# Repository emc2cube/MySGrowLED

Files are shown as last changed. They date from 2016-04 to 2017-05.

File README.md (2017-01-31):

MySGrowLED
==========

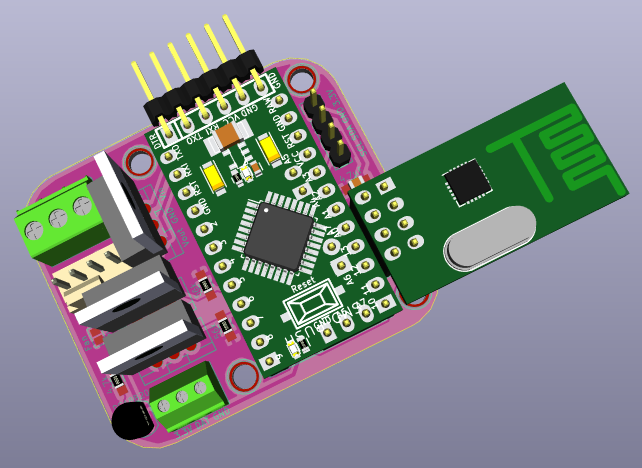
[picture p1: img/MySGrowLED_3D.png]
KiCad 3D view


Description
-----------

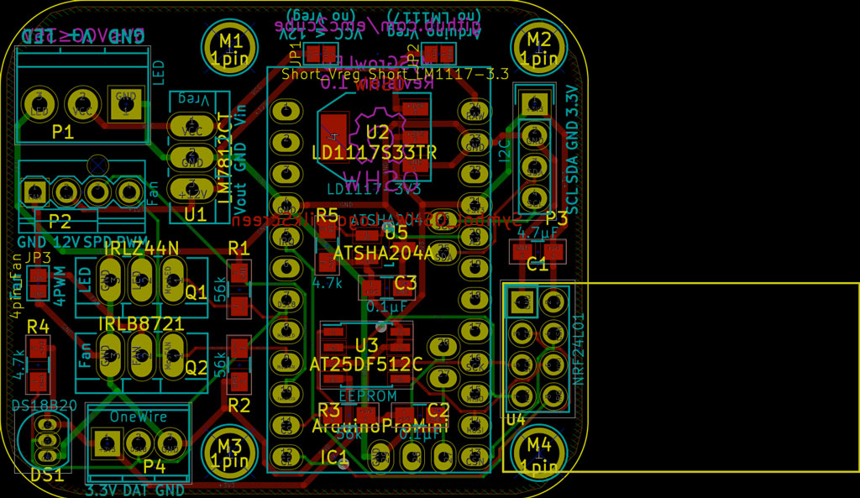
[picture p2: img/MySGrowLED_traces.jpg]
KiCad traces


[MySensors](http://www.mysensors.org) module designed for wireless greenhouse automation (nRF24L01, 2.4GHz).

This module allow you to:
- control a primary LED light (5-40V input can be used to power the module)
- control a secondary circuit designed for a CPU PWM fan but can be used for a second light, humidifier, relay or anything else using 12V
- monitor temperature using an optional onboard DS18b20 sensor
- monitor external temperature by plugging external OneWire sensors
- monitor any additional parameters using additional I2C modules such as temperature, humidity, light levels, barometric pressure, etc...

Ordering
--------

Gerber files are included, so you can order these PCB at your favorite PCB fab house.
For an easy ordering process you can directly order these PCB from different manufacturer without having to do anything:
- [PCBs.io](https://PCBs.io/share/4oldQ) 4 for $11.62, black 1.2mm PCB, ENIG finish.
- [DirtyPCBs](http://dirtypcbs.com/store/designer/details/10880/873/mysgrowled) ~10 for $15.95, multiple colors and PCB thickness, HASL finish.
- [OSH Park](https://oshpark.com/shared_projects/yTV72xyU) 3 for $14.95, purple 1.6mm PCB, ENIG finish.
Components are highly customizable and the default list may not be the best for your specific use, but it will work for most of the cases. Double check that the power supplies, voltage regulators and mosfets are compatible with your project.

Options
-------

This board is designed to be compatible with [MySensors](http://www.mysensors.org) but can be used on its own (timer or sensors to control the lights) or another system using 2.4GHz communication if you adapt the arduino code.

### ATSHA204 module
For security reason you can add a CryptAuthEE SHA256 chip. This will allow you to sign messages and will secure communications between the node and your gateway (this is not encryption, just signing).
If you only control lights, fan, or other non-essential hardware you probably don't need to bother with this chip.
Signing can also be done at the software level, without the chip if you decide to add this function later.

### Eeprom module
This module is only used to perform OTA updates on the node. If you don't plan to use this feature you can also skip this chip.
You will also need to burn a compatible bootloader to your arduino (DualOptiBoot)

Assembly
--------

Once you received your dirty package of PCBs (or any other Fab house) start by inspecting it carefully to look for scratches, dents, or anything that seems wrong. Do not use the board if you have any concerns.
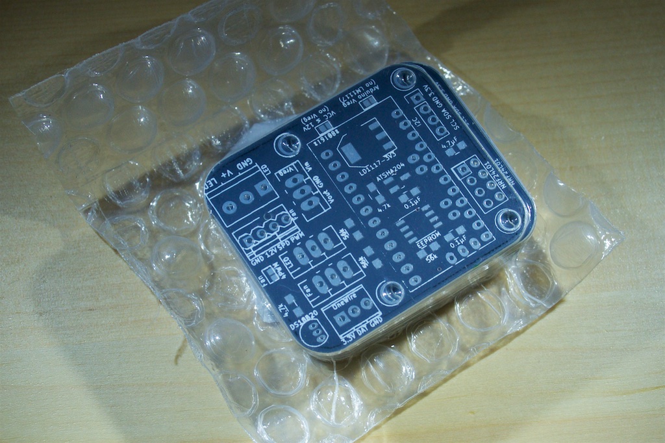
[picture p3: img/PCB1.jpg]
DirtyPackage


Markings are a little off, but nothing wrong on this one, good to go!
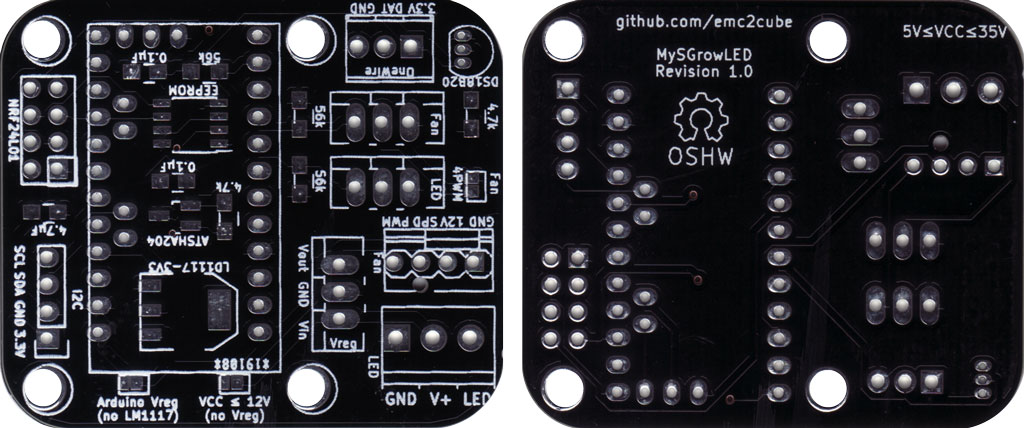
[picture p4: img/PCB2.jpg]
PCB RV


Start by soldering the optional chips, if you plan to use them.
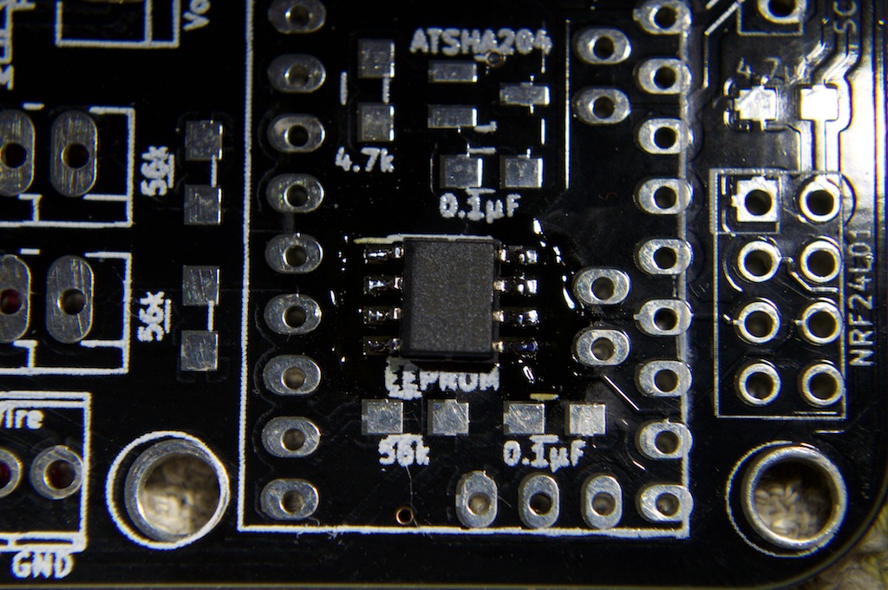
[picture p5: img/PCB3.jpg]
Eeprom soldering

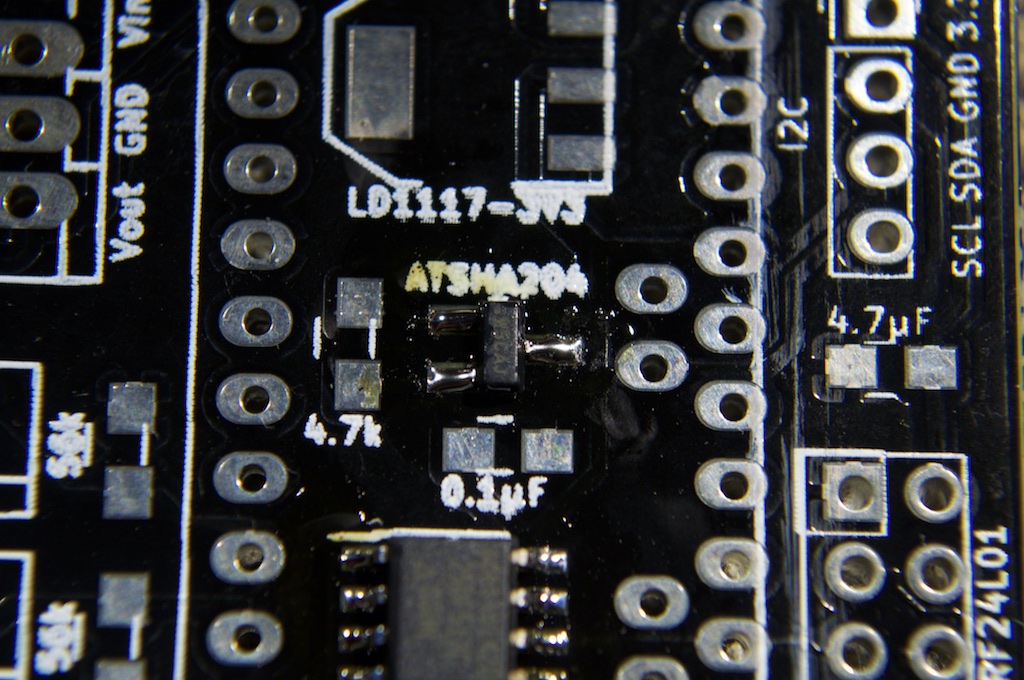
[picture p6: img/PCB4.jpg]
ATSHA soldering


Then add all other surface mount components. Don't be affraid by their little size, they are actually easy to solder. If you never soldered SMD components before, be sure to look for a few video tutorials first.
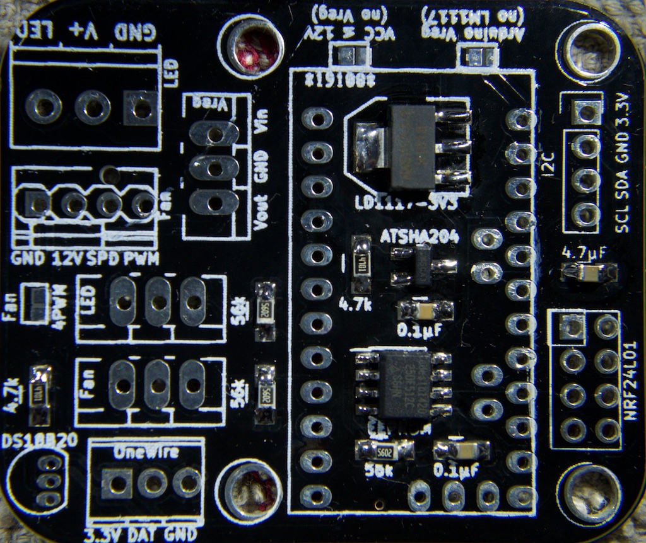
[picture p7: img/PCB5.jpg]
SMD soldering


Finish by adding the regular through-hole components, starting by the smaller ones.
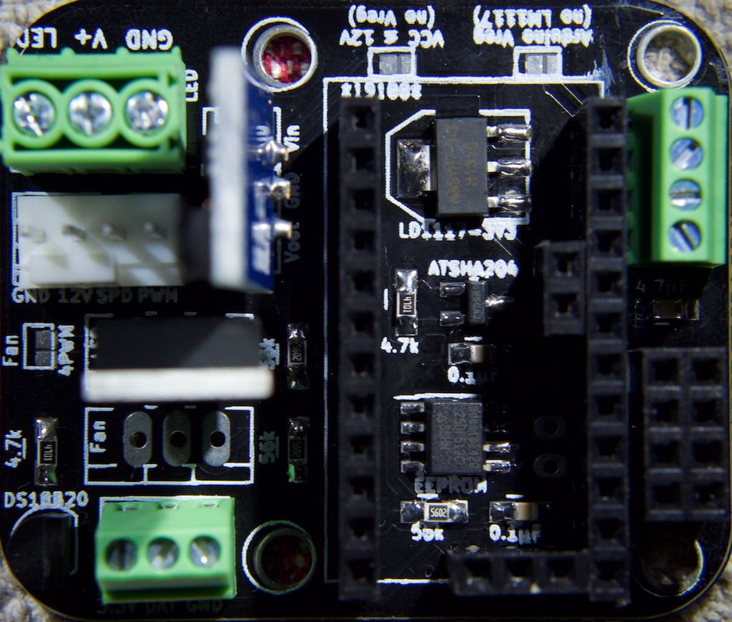
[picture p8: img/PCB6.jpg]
Components and terminals


Plug your arduino module and radio and you are good to go.
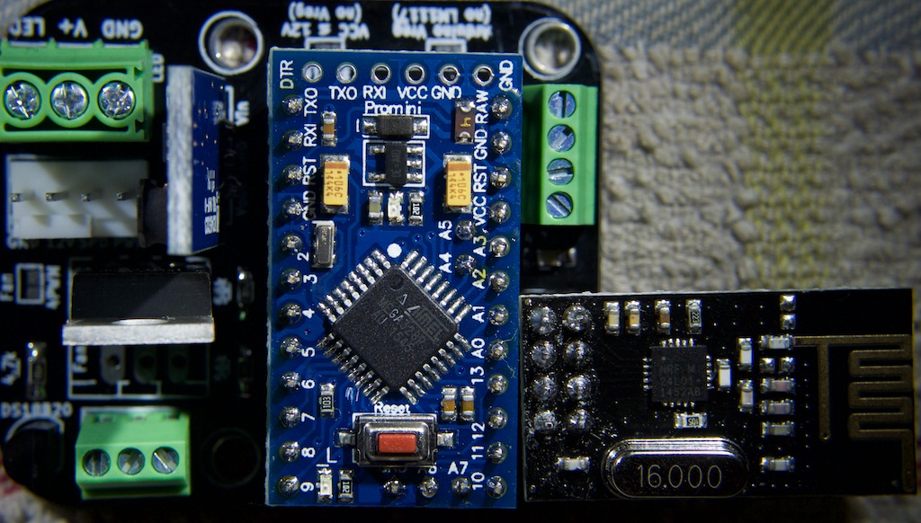
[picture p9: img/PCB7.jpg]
Arduino and radio


Testing
-------

You can upload MySGrowPCB_test to your arduino to test the setup:
- It will look for an ATSHA204 and return its serial number if detected.
- It will look for an eeprom and return its manufacturer ID if detected.
- It will alternatively switch the LED and Fan circuits ON and OFF for 10 seconds.

Usage examples
--------------

This module can be used on the DIY LED light example included (PCB compared to breadboard design)
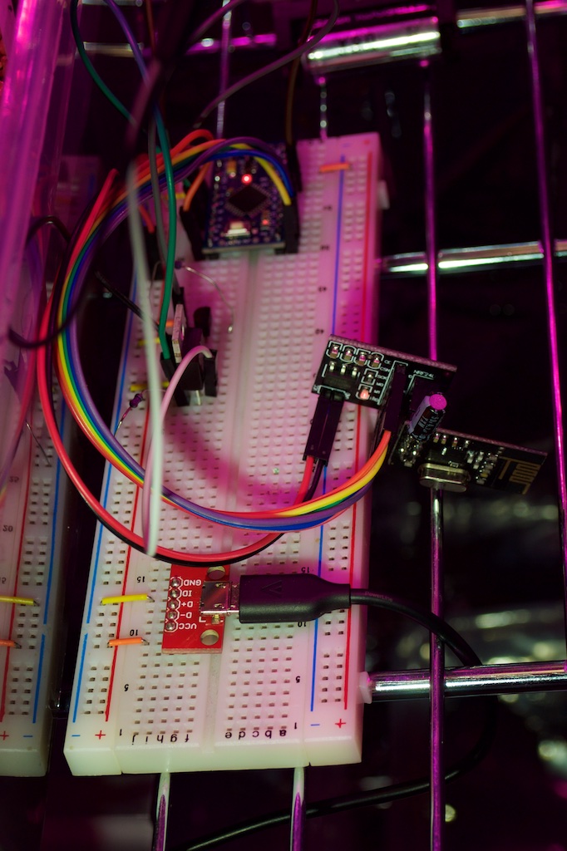
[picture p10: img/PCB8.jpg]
PCB vs BreadBoard

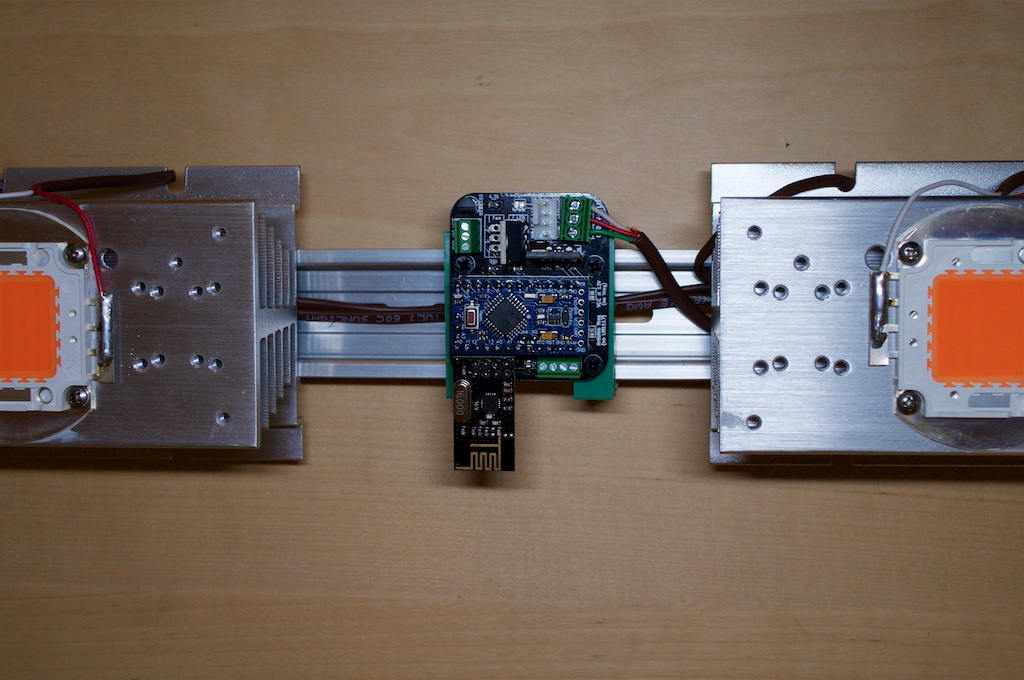
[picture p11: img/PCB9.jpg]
MySGrowLED


Another possible use to control a germination chamber inside a plastic container (PCB compared to previous protoboard design) 
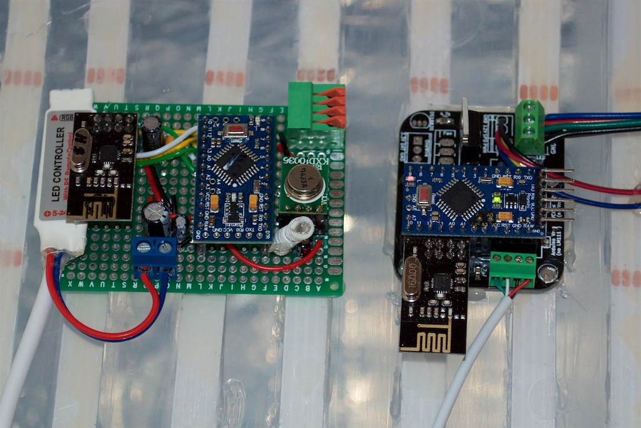
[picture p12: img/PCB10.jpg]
PCB vs ProtoBoard

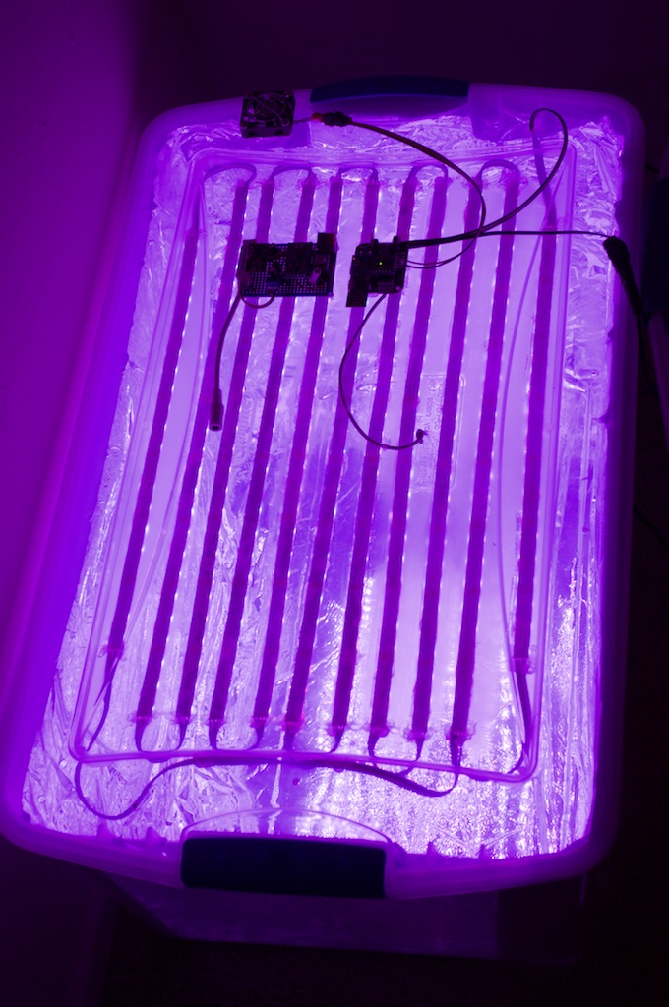
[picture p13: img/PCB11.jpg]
SeedBox


Revision history
----------------

Version 1.0: Initial release.

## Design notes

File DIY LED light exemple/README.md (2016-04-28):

DIY 60W (3*20W) grow LED bar
============================

Disclaimer
----------
This section is only an example of what can be done. Consider this guide as an illustration or just as a way for me to consolidate all useful information on my setup for future use. No support provided!
It will give you general directions but you will probably want to customize it to fit your grow space, greenhouse, etc.
This setup is currently working so if you tried to recreate it on your side using the same components from the same source and following all steps and it's not working then it's probably because:
- One of the component is defective.
- You did something wrong.

Components
----------
Total cost in parts is ~$95 for a *real* 60W LED light with a spectrum optimized for plant growth and photosynthesis (no green).
Most of the commercial solutions are extremely deceptive on their real output an power usage. In this example, as we are using 3*50W chips, this would typically be advertised as a 150W light.
This is totally wrong as only 60W of power will be used. It is not advised to run a LED chip at its nominal power as it will generate a lot of heat and will fail quickly!

To create this 60W LED fixture you will need the following materials:
- 3*50W full spectrum 45mil COB LED ($30, [~$10](http://www.ebay.com/itm/321822518554) each).
Can be bought on [ebay](http://www.ebay.com/itm/321822518554), [aliexpress](http://www.aliexpress.com/store/product/5pcs-400nm-840nm-Full-Spectrum-led-grow-chip-10W-20W-30W-50W-100W-30mil-45mil-led/1393057_32597667622.html), etc.
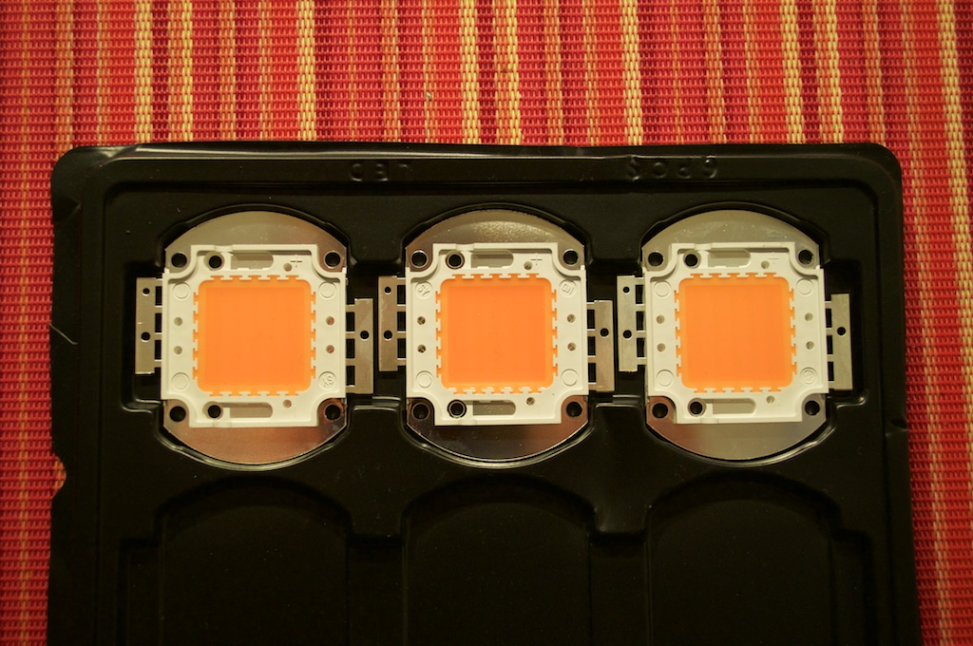
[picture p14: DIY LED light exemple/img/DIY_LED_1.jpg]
LED Chips


- 3*heatsinks able to cool down your LED modules ($30, [~$10 each](http://www.ebay.com/itm/231185535248)).
In this case we will be using a [DC-HS11132 heatsink](http://store3.sure-electronics.com/dc-hs11132) for passive cooling.
Heatsink come with 4 to 16 M3 screws and a pack of thermal paste for improved heat dissipation.
Using a smaller heatsink, or running more power in the LEDs would require a fan. Using this setup, the whole assembly is at ~40°C while running which is safe for the plants even at a close distance.
This specific heatsink can be mounted on a 35mm DIN rail which will allow to link the 3 LEDs on a single bar fixture.
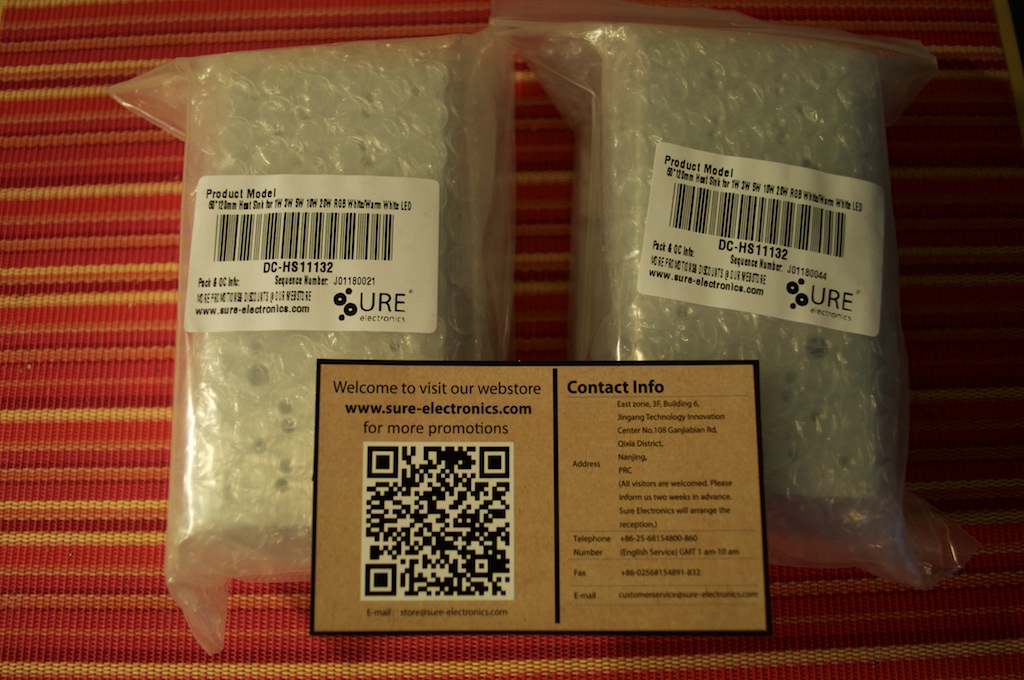
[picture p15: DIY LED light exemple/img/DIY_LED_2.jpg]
Heatsinks


- 1*mounting track, 35mm DIN rail Type, 1m length, ([~$7](http://www.mouser.com/ProductDetail/Schneider-Electric/16-700DIN/)).
I used a [16-700DIN](http://magnecraft.thomasnet.com/item/all-categories/accessories/pn-3042) from [Schneider Electric](http://www.serelays.com).
Heatsink will slide on the rail and then can be bolted to it using the existing holes in the rail.

- 1*60W LED driver to power the LEDs ([~$16](https://www.jameco.com/webapp/wcs/stores/servlet/Product_10001_10001_2100540_-1)).
I use a [LPC-60-1750](http://www.meanwell.com/mw_search/LPC-60/LPC-60-SPEC.PDF) from [Mean Well](http://www.meanwell.com) that will provide 34V at 1750mA. LEDs will be wired in serial.
As this unit will be in charge of converting your main power (110-230V) to ~34V for more than 12h a day, every day, in potentially humid conditions it is very important to choose a power supply you can trust. You don't really want it to catch fire.
I would not recommend buying the power supply from ebay or directly from china as you may end up with a counterfeit unit unless you are sure of the seller.

- 1*PCB DIN rail mounting bracket ([~$2](http://www.ebay.com/itm/181561948236))
Will be used to mount the PCB to the rail. This is optional, if you prefer using a timer, a switch or have another way to control your light you can use this LED fixture as a standalone without the MySGrowLED part. But in this case I wonder why you are on this page.

- Misc (~$10)
You will also need some basic supplies that you may already have, or will find at your local hardware store. You will also need to solder the wires to the LED chip.
In this case you will need ~3m of [solid 2-conductor cable](http://www.lowes.com/pd_70086-295-64162101_1z0v13b__?productId=4294345&pl=1) and ~40cm of [solid 3-conductor cable](http://www.lowes.com/pd_70087-295-64168802_1z0v13b__?productId=3379310&pl=1) (optional if you are not using MySGrowLED).
I used thermostat cable that can easily bought in roll or cut at your size at your local store.
You will also need some wire terminal blocks to connect the wires, hex bolts and nuts to secure the heatsinks to the rail, some rope, hooks or any other way to suspend the LED fixture to your grow area.

Assembly
--------
The whole process should not take too much time, probably around 1 hour without rushing it.

### LED assembly
Start by removing the heatsinks from their package. They should come with at least 4 screws and a small pack of thermal paste.
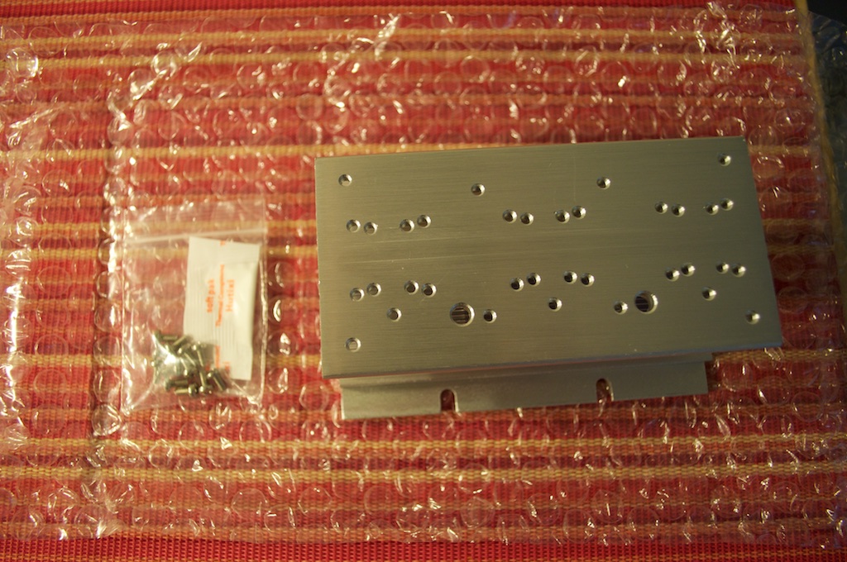
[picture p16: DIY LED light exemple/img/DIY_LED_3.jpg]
Heatsinks unboxed


Grab a LED chip and lay it face down on a soft nonabrasive surface.
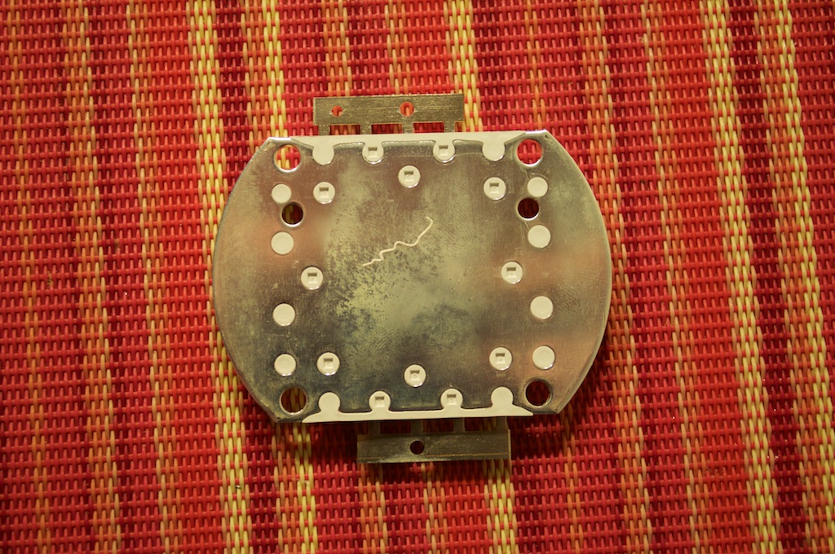
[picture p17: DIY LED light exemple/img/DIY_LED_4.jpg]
Chip back


Locate the thermal paste and carefully tear it open.
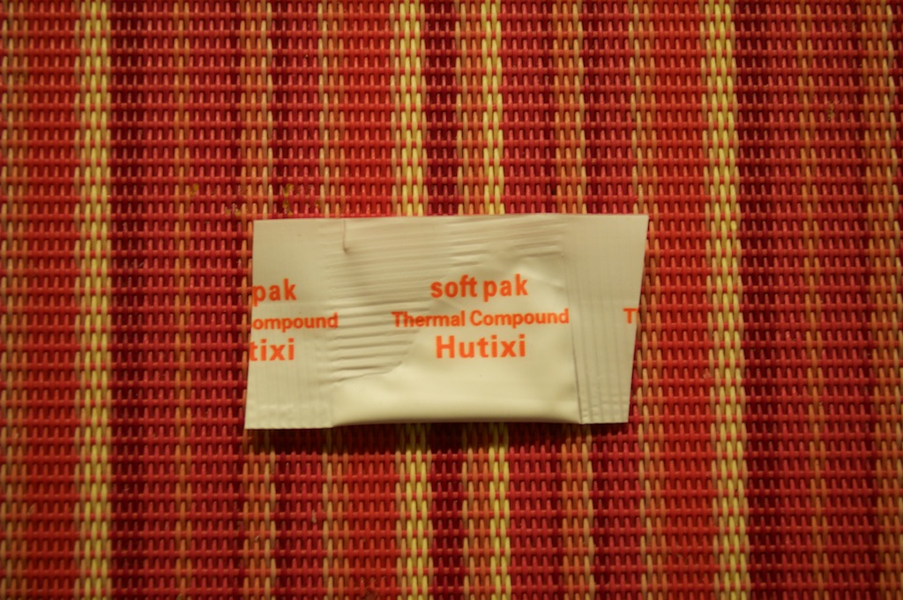
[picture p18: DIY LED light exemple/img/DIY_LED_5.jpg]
Thermal paste packet


Empty the whole packet content over the LED metal back...
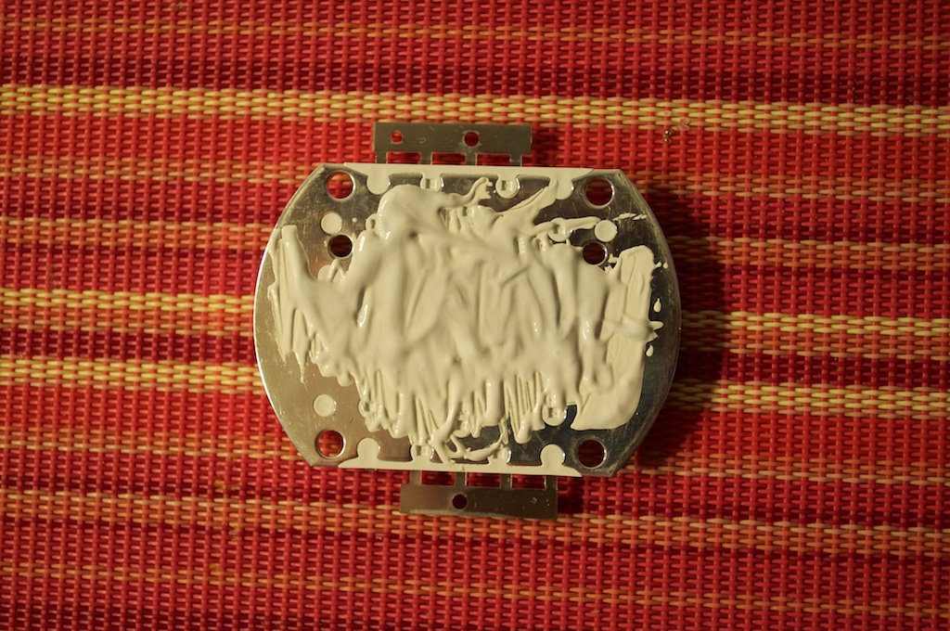
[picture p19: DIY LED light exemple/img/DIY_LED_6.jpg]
Paste on chip


... and spread it evenly over all the back surface.
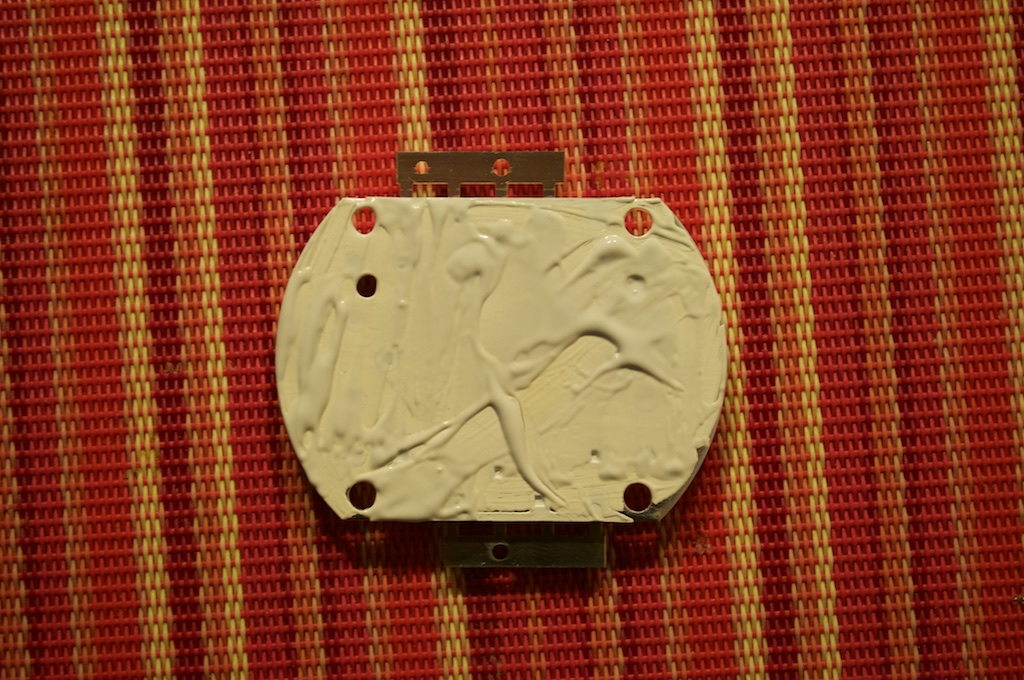
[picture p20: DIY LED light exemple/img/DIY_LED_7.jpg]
Spread


Grab the LED chip and using the provided screws mount it on the heatsink. Do not screw tight each screw one by one but do it in multiple steps to spread the paste evenly.
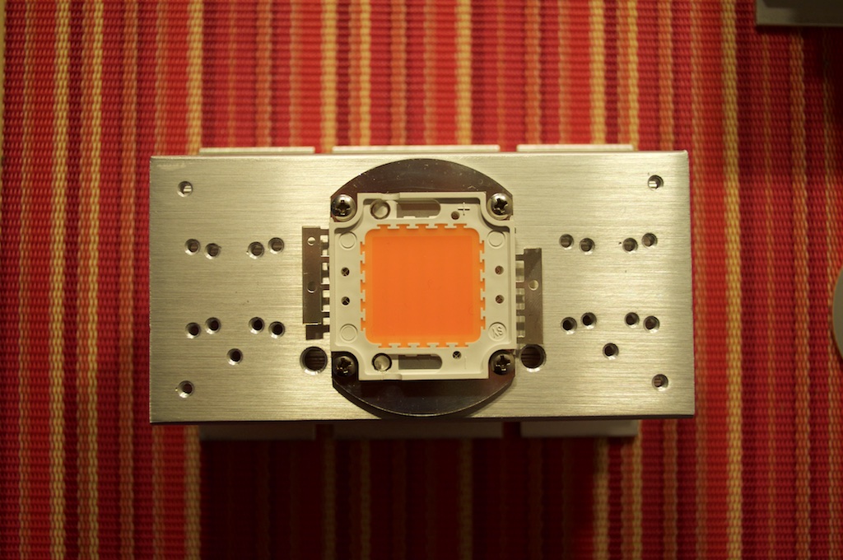
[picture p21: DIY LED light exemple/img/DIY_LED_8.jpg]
Screw


Repeat for the 2 other LED chips and heatsinks.
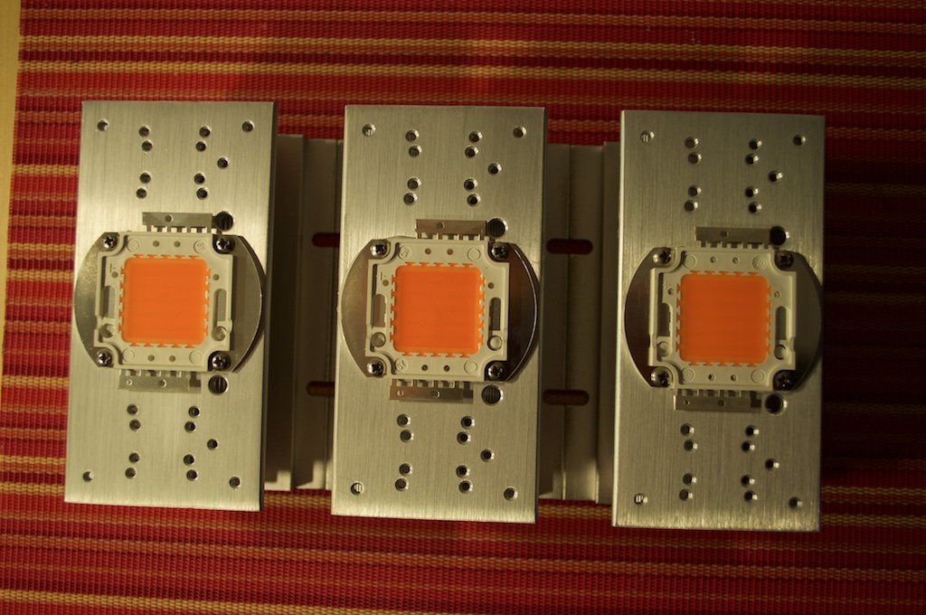
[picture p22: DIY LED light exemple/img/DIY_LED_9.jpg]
Repeat


### Soldering
Cut your 2-conductor cable in ~1m segments. Decide which color will be the positive wire (red in my case) and negative (white).
Locate the positive and negative contacts on the LED. They are the tiny metal wings on each side of the LED. Usually the positive side is perforated with 2 holes while the negative side only have 1 hole. You may want to check this using a multimeter. If at the end your lights don't light up it's probably reversed on your LEDs. Don't worry, just switch the wires on the terminal connector (see below).

Remove the plastic insulator over ~1cm and solder the wire directly to the LED chip connector. Use as much solder as possible to create a good electric contact.
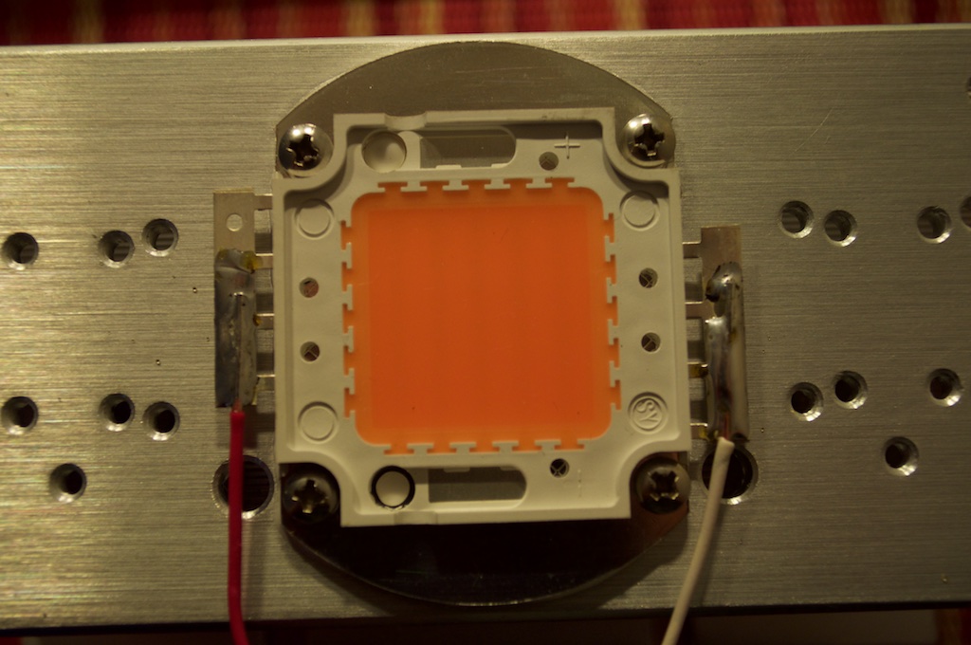
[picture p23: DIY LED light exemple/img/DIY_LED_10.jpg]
Soldered


Repeat the process for each LED unit.

### Final assembly
Now that all units are ready you need to create the fixture using the rail.
Bend the cable around the heatsink to have it sandwiched between the heatsink and the rail. All wires should be oriented the same way, toward your power supply output.

Slide all heatsinks to their definitive position and secure them to the rail.
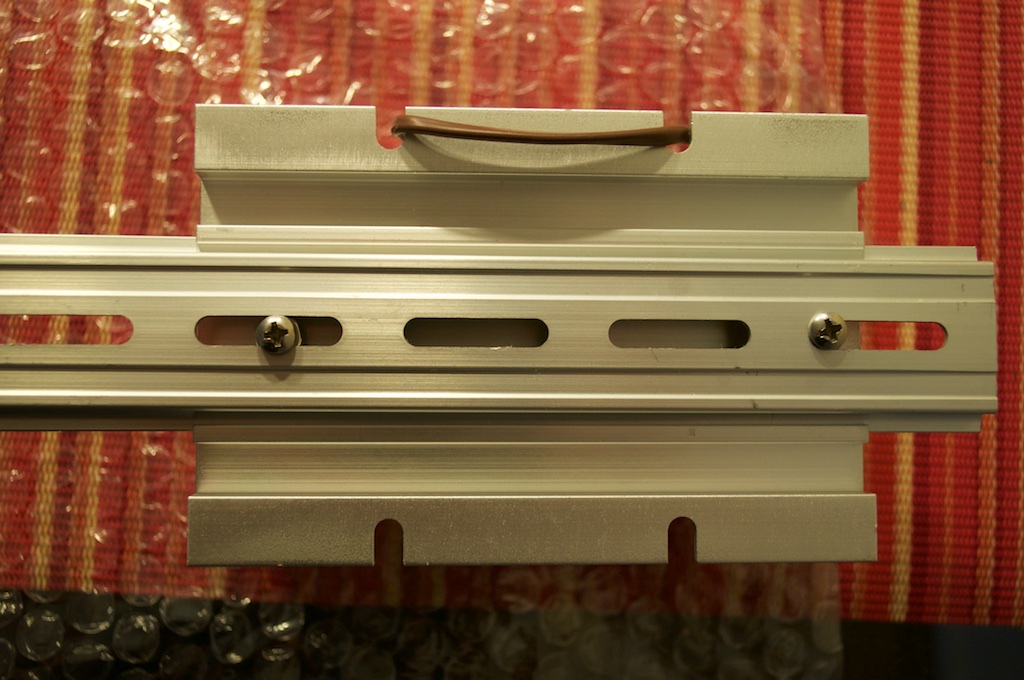
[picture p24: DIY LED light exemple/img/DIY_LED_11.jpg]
Secured


On the end where all your wires are converging, thread the 2-connector cables into the second DIN rail hole. Thread the 3-conductor in the first hole (if using MySGrowLED) toward the second heatsink.
Use a terminal connector to link all 2-connector wires together according to their polarity. On the other side link the 3-conductor using the same colors, leaving the extra color alone.
Secure the terminal to the rail using a zip-tie.
If you are using MySGrowLED link the positive output of the power supply to the positive side of your LEDs (red wire in my case) and the negative output of the power supply *to the extra color of the 3-conductor wire* (green in my case). If you are using a different control circuit link the negative output of the power supply output directly to the negative side of your LEDs (would be white wires in this case). If your lights are not working, probably because of a polarity error, switch the wires at the terminal, no need to desolder the wires!
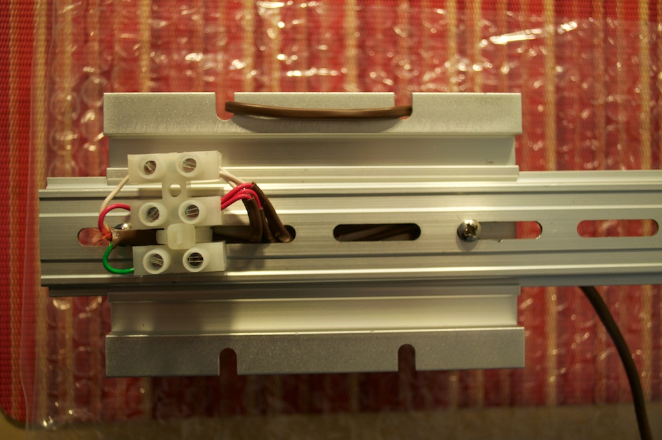
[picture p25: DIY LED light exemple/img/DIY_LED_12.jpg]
Wiring


Add some rope, chain, hooks or other to suspend the LED fixture to your grow space.
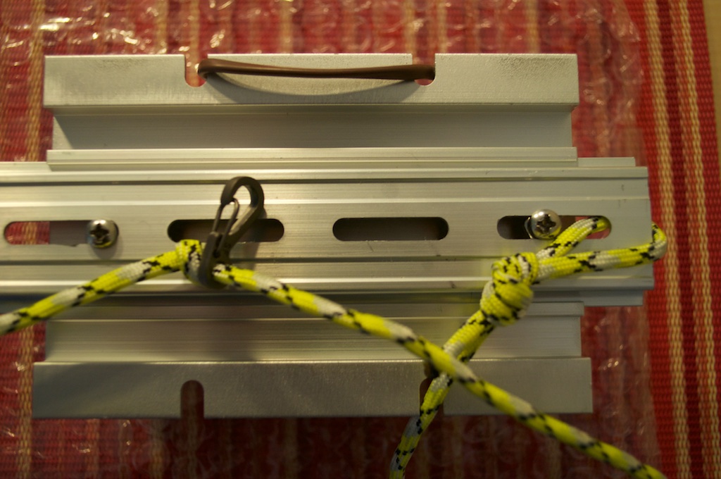
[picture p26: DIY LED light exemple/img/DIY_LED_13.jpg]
Rope and hook


Mount everything (in my case suspended to a [$25 IKEA OMAR shelving unit](http://www.ikea.com/us/en/catalog/products/00069768/#/10069763))
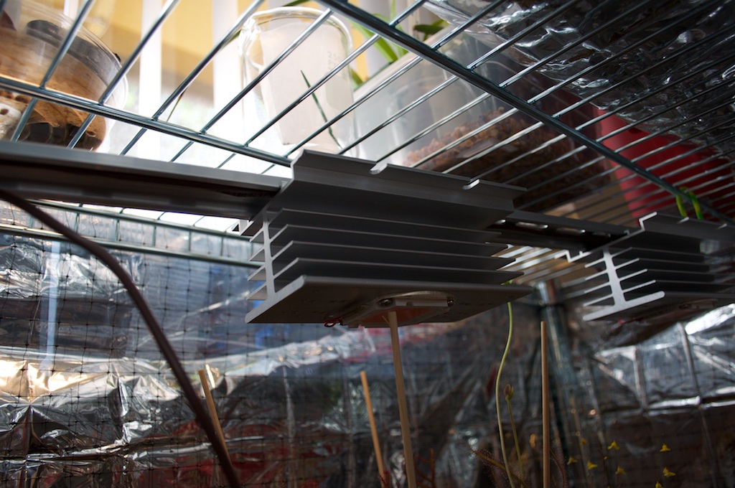
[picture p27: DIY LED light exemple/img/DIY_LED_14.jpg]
LEDs mounted


Plug the power supply to the electrical main and congratulations, you now have a LED grow light!
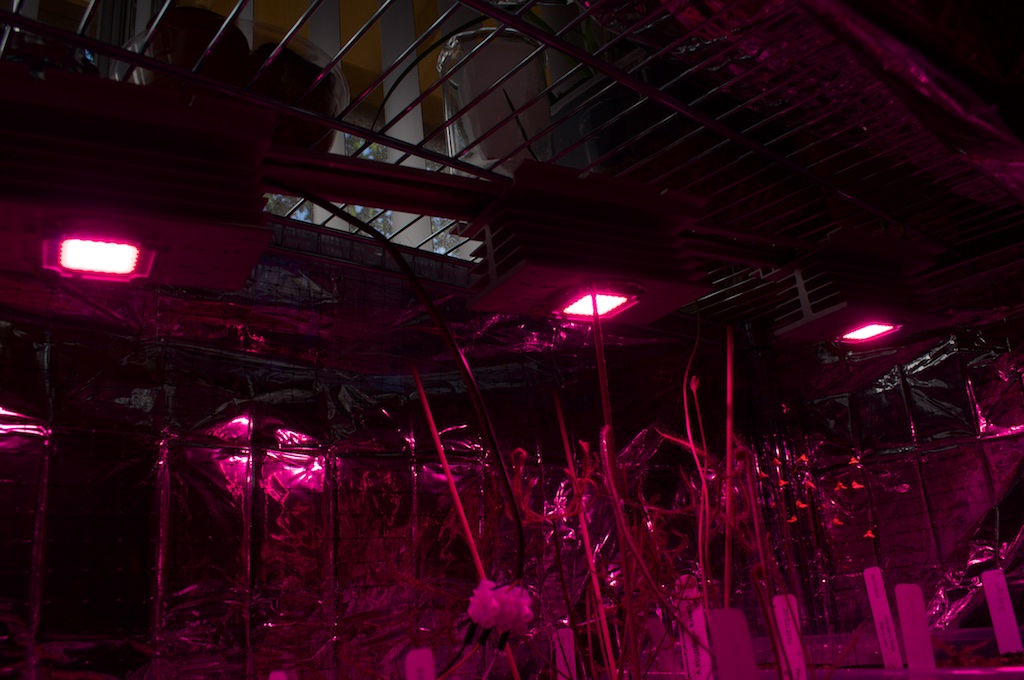
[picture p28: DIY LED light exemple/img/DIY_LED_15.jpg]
LEDs on


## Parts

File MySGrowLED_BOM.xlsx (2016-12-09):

Quantity | Part | Value | Package | Manufacturer | Manufacturer P/N | Mouser P/N | Comment | Aliexpress or Ebay link
1 | C1 | 4.7µF | SMD 0805 | Murata | GRM21BR61C475KA88K | 81-GRM21BR61C475KA8K |  | http://www.aliexpress.com/item/1LOT-100PCS-Chip-Capacitors-4-7uF-475K-16V-10-0805-Package0805-2012-Metric/32561376020.html
2 | C2, C3 | 0.1µF | SMD 0805 | Murata | GRM21R71C104JA01D | 81-GRM21R71C104JA01D |  | http://www.aliexpress.com/item/1LOT-100PCS-Chip-Capacitors-0-1uF-104K-16V-10-0805-Package0805-2012-Metric/32560085454.html
3 | R1, R2, R3 | 56k | SMD 0805 | Bourns | CR0805-JW-563ELF | 652-CR0805JW-563ELF |  | http://www.aliexpress.com/item/100pcs-lot-SMD-Chip-Resistor-1-0805-56K-1-8W-100-YAGEO-New-Original-Chip-Fixed/32570183133.html
2 | R4, R5 | 4.7k | SMD 0805 | Bourns | CR0805-JW-472ELF | 652-CR0805-JW-472ELF |  | http://www.aliexpress.com/item/100pcs-lot-SMD-Chip-Resistor-1-0805-4-7K-4700-OHMS-1-8W-100-YAGEO-New/32570155447.html
1 | P1 | LED | 3.5mm pitch | Phoenix Contact | 1984620 | 651-1984620 | Optional, direct soldering | http://www.aliexpress.com/item/20pcs-3-5mm-Pitch-3-pin-Straight-Pin-PCB-Screw-Terminal-Blocks-Connector-NEW/32427573697.html
1 | P2 | Fan | 2.54mm pitch | Molex | 47053-1000 | 538-47053-1000 | Optional, direct soldering
1 | P3 | I2C | 2.54mm pitch | Phoenix Contact | 1725672 | 651-1725672 | Optional, direct soldering | http://www.aliexpress.com/item/10pcs-4-Poles-4-Pin-2-54mm-0-1-PCB-Universal-Screw-Terminal-Block-Connector/32417814976.html
1 | P4 | OneWire | 2.54mm pitch | Phoenix Contact | 1725669 | 651-1725669 | Optional, direct soldering | http://www.aliexpress.com/item/100pcs-3-Poles-3-Pin-2-54mm-0-1-PCB-Universal-Screw-Terminal-Block-Connector/32417810166.html
1 | Q1 | IRLZ44N | TO-220 | International Rectifier | IRLZ44NPBF | 942-IRLZ44NPBF | Replace N-Mosfet accordingly to LEDs requirements | http://www.aliexpress.com/item/10PCS-IRLZ44NPBF-IRLZ44N-TO220-50A-60V-New-and-original/32330563148.html
1 | Q2 | IRLB8721 | TO-220 | International Rectifier | IRLB8721PBF | 942-IRLB8721PBF | Optional if 4 pin PWM Fan, close JP3 | http://www.aliexpress.com/item/Free-shipping-10pcs-lot-IRLB8721PBF-TO-220-30V-62A-new-original/32559660851.html
1 | DS1 | DS18B20 | TO-92 | Maxim Integrated | DS18B20+ | 700-DS18B20+ | Optional | http://www.aliexpress.com/item/Free-Shipping-20pcs-DALLAS-DS18B20-18B20-18S20-TO-92-IC-CHIP-Thermometer-Temperature-Sensor/32236763433.html
1 | U1 | 12V switching Vreg | TO-220 | Murata | 580-7812SR-C | 580-7812SR-C |  | http://www.aliexpress.com/item/Free-shipping-10pcs-lot-1-5A12V-three-terminal-regulator-L7812CV-L7812-KA7812-LM7812-LM7812CT-TO220-new/32517356484.html
1 | U2 | 3.3V linear Vreg | SOT-223 | Texas Instruments | TLV1117-33CDCYR | 595-TLV1117-33CDCYR |  | http://www.aliexpress.com/item/S1065-Free-shipping-100pcs-AMS1117-3-3-SOT-223-3-3V-Linear-Regulator-LM1117/32351569056.html
1 | U3 | AT25DF512C | SOIC-8 | Adesto Technologies | AT25DF512C-SSHN-B | 988-AT25DF512CSSHN-B | Optional, for OTA
1 | U4 | 2x4 pin 2.54mm pitch female header |  |  |  |  | Required to use mount screw below NRF24L01 | http://www.aliexpress.com/item/Free-shipping-Brand-New-High-Quality-10pcs-2x4-Pin-8P-2-54mm-Double-Row-Female-Straight/32402809934.html
1 | U5 | ATSHA204A | SOT-23 | Atmel | ATSHA204A-STUCZ-T | 566-ATSHA204ASTUCZ-T | Optional, for signing
1 | IC1 | ArduinoProMini |  | Arduino | Pro Mini 3.3V |  |  | http://www.aliexpress.com/item/1pcs-lot-Pro-Mini-328-Mini-3-3V-8M-ATMEGA328-ATMEGA328P-AU-3-3V-8MHz-for/32313595044.html
1 |  | NRF24L01 |  | Radio module | NRF24L01+ | 713-113990011 |  | http://www.aliexpress.com/store/product/Free-shipping-20-pcs-lot-NRF24L01-wireless-module-24L01-upgraded-version-2-4G-wireless-module/1022067_1569362725.html
2 |  | 2.54mm 12pin female single row pin |  |  |  |  |  | http://www.aliexpress.com/item/10PCS-2-54mm-40-Pin-Stright-Female-A1:I25-Pin-Header-Strip-PCB-Connector/32597304567.html
2 |  | 2.54mm 2pin female single row pin |  |  |  |  |  | http://www.aliexpress.com/item/10PCS-2-54mm-40-Pin-Stright-Female-A1:I25-Pin-Header-Strip-PCB-Connector/32597304567.html
1 |  | 2.54mm 3pin female single row pin |  |  |  |  |  | http://www.aliexpress.com/item/10PCS-2-54mm-40-Pin-Stright-Female-A1:I25-Pin-Header-Strip-PCB-Connector/32597304567.html
0 | JP1 | Short_Vreg | PCB trace | Solder jumper |  |  | close if VCC ≤ 12V
0 | JP2 | Short_LM1117-3.3 | PCB trace | Solder jumper |  |  | close if 3.3V regulator is not used
0 | JP3 | 4pin_Fan | PCB trace | Solder jumper |  |  | close if 4 pin PWM CPU fan is used and Q2 not present

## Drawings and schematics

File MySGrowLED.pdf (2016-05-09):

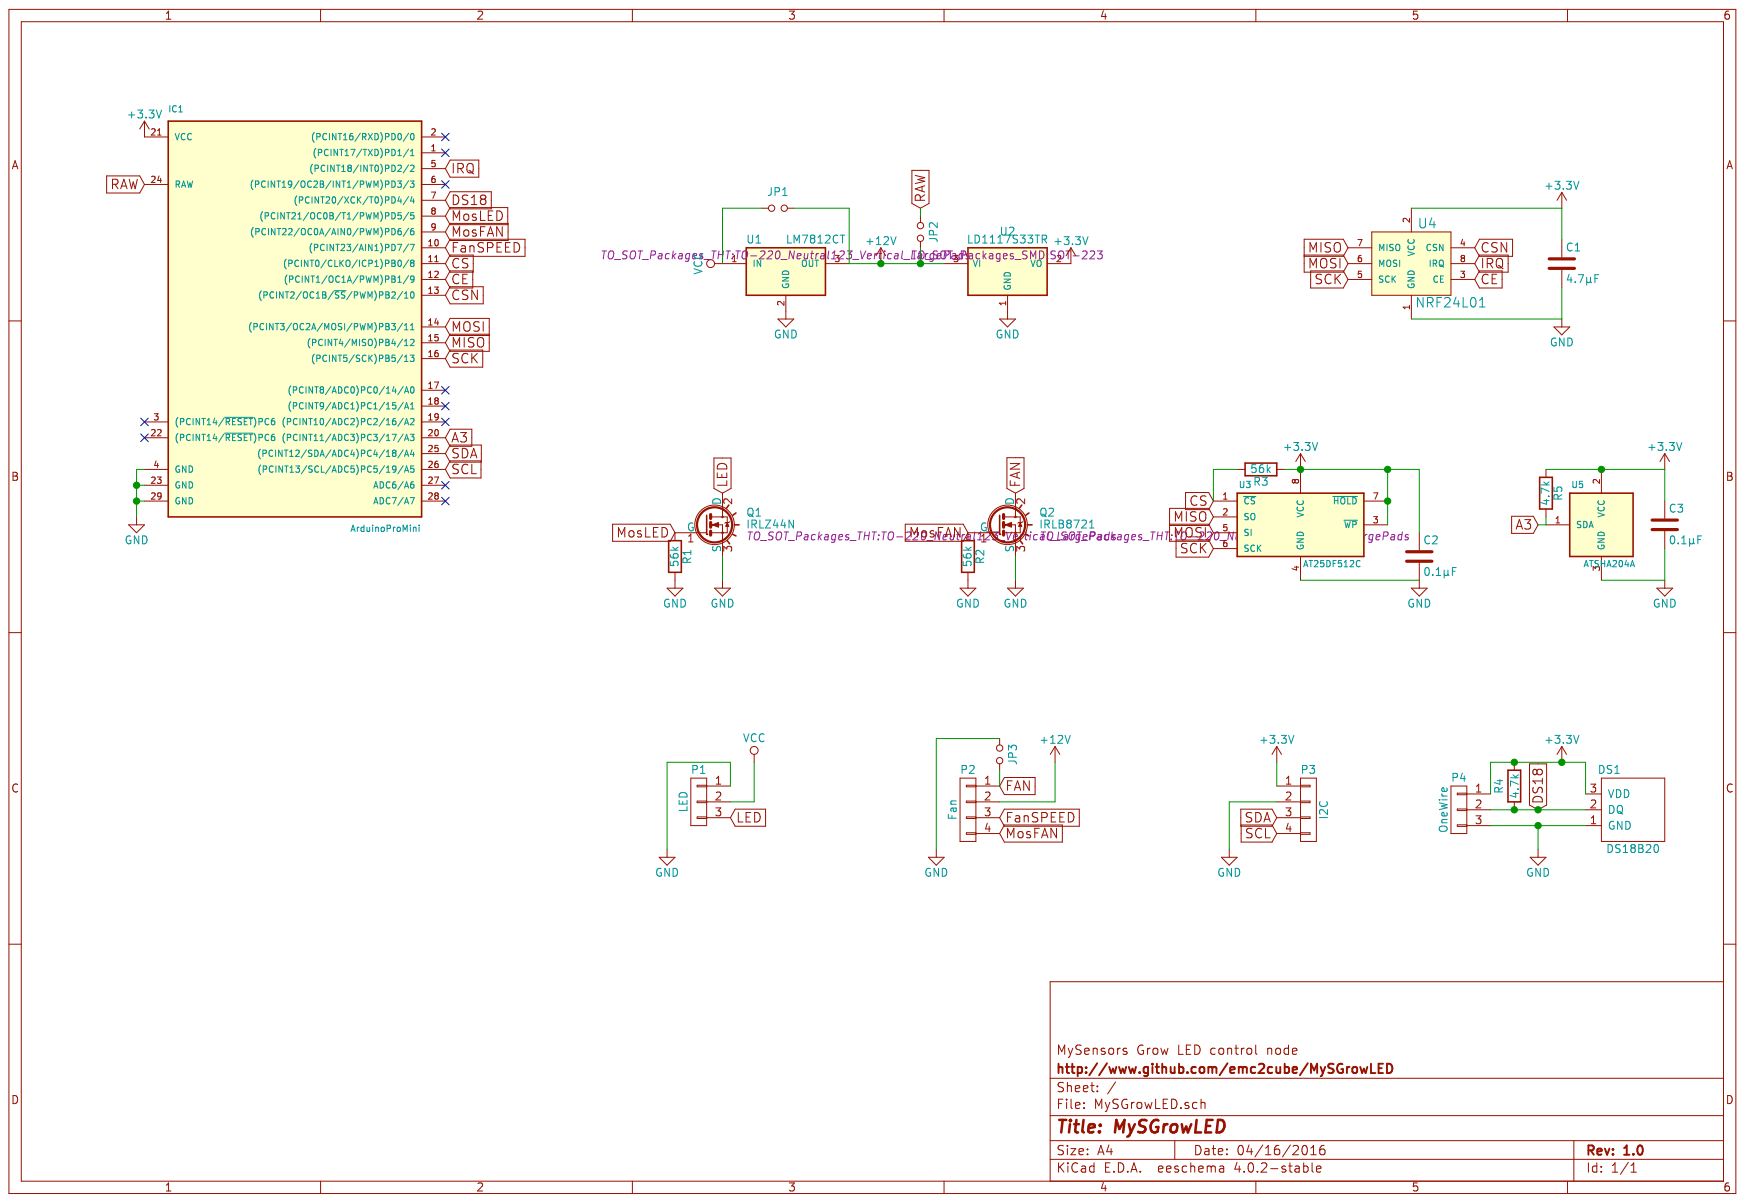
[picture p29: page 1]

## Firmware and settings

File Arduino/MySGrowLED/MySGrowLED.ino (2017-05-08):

//////////////////////////
//     Configuration    //
//////////////////////////

// Customize your device name. Ex: "Greenhouse", "Grow rack", "Top shelf", etc...
String Location = "Plants";       // Location of the device, will be sent to the gateway with each device

// Enable/disable each module according to your hardware configuration
#define LED_CONTROL               // Enable to control a device using LED mosfet
#define FAN_CONTROL               // Enable to control a device using Fan mosfet or by PWM
//#define TEMPHUM_SENSOR            // Enable to monitor temperature and humidity using a SI7021 I2C module
//#define LUX_SENSOR                // Enable to monitor light level using a BH1750 I2C module
//#define DALLAS                    // Enable temperature monitoring using optional onboard dallas sensor or via OneWire terminal

// Use custom static node ID
// If disabled node ID will be automatically assigned
//#define MY_NODE_ID 42

// Use custom parent node ID. Use 0 to force direct connection to the gateway.
// If disabled node ID will be automatically assigned
//#define MY_PARENT_NODE_ID 0

// Enable repeater feature for this node
//#define MY_REPEATER_FEATURE

// Advanced options
// Use low power transmission for RF24, better signal/noise ratio but shorter range
//#define MY_RF24_PA_LEVEL RF24_PA_LOW
// Enable OTA feature
//#define MY_OTA_FIRMWARE_FEATURE         // Require eeprom (U3) on the PCB
// Enable message signing
//#define MY_SIGNING_ATSHA204             // Require ATSHA205 (U5) on the PCB and configured with your system key
// Enable debug prints to serial monitor
//#define MY_DEBUG

//////////////////////////
// End of configuration //
//////////////////////////

// MySensors
#define MY_RADIO_NRF24          // Enable and select radio type attached
#include <SPI.h>
#include <MySensors.h>
#define SN "MySGrowLED"         // Name of the sketch
#define SV "2.1.1"              // Version (2.x : use MySensors 2.x)
boolean metric = true;          // Use SI by default
#define MESSAGEWAIT 500         // Wait a few ms between radio Tx

#if defined LED_CONTROL
#define MosLED_PIN 5            // Arduino pin attached to MOSFET Gate pin
#define CHILD_ID_LED 0
#define EPROM_LED_LEVEL 1
#define FADE_DELAY 10           // Delay in ms for each percentage fade up/down (10ms = 1s full-range dim)
static int currentLEDlevel = 0;
MyMessage msgPercLED(CHILD_ID_LED, V_PERCENTAGE);
MyMessage msgStatLED(CHILD_ID_LED, V_STATUS);
#endif

#if defined FAN_CONTROL
#define MosFAN_PIN 6            // Arduino pin attached to MOSFET Gate pin or fan 4th pin (PWM)
#define CHILD_ID_FAN 1
#define EPROM_FAN_LEVEL 2
static int currentFANlevel = 0;
MyMessage msgPercFAN(CHILD_ID_FAN, V_PERCENTAGE);
MyMessage msgStatFAN(CHILD_ID_FAN, V_STATUS);
#endif

#if defined TEMPHUM_SENSOR
#include <Wire.h>
#include "i2c_SI7021.h"
#define CHILD_ID_TEMP 2
#define CHILD_ID_HUM 3
SI7021 si7021;
const unsigned long SLEEP_TEMPHUM = 150000;  // Sleep time between TempHum reads (in milliseconds), default 2min30 (150000ms)
unsigned long TempHumMillis = 0;
MyMessage msgTemp(CHILD_ID_TEMP, V_TEMP);
MyMessage msgHum(CHILD_ID_HUM, V_HUM);
#endif

#if defined LUX_SENSOR
#include <Wire.h>
#include <BH1750.h>
#define CHILD_ID_LUX 4
BH1750 lightSensor;
const unsigned long SLEEP_LUX = 150000;  // Sleep time between light levels reads (in milliseconds), default 2min30 (150000ms)
unsigned long LuxMillis = 0;
MyMessage msgLux(CHILD_ID_LUX, V_LIGHT_LEVEL);
#endif

#if defined DALLAS
#define ONE_WIRE_BUS 4                      // Pin where dallas sensor(s) is(are) connected
#define CHILD_ID_DALLAS 5
int numSensors = 0;
const unsigned long SLEEP_DALLAS = 150000;  // Sleep time between temperature reads (in milliseconds), default 2min30 (150000ms)
unsigned long DallasMillis = 0;
#include <OneWire.h>
#include <DallasTemperature.h>
OneWire oneWire(ONE_WIRE_BUS);
DallasTemperature dallas(&oneWire);
MyMessage msgDallas(CHILD_ID_DALLAS, V_TEMP);
#endif


void setup()
{
  metric = getControllerConfig().isMetric;  // was getConfig().isMetric; before MySensors v2.1.1

#if defined LED_CONTROL
  pinMode(MosLED_PIN, OUTPUT);
  //Fetch the last light state from the eprom
  currentLEDlevel = loadState(EPROM_LED_LEVEL);
  Serial.print(F("Led eprom state: "));
  Serial.print(currentLEDlevel > 0 ? F("ON, ") : F("OFF, "));
  Serial.print(currentLEDlevel);
  Serial.println(F("%"));
  fadeToLEDLevel(currentLEDlevel);
#endif

#if defined FAN_CONTROL
  pinMode(MosFAN_PIN, OUTPUT);
  //Fetch the last fan state from the eprom
  currentFANlevel = loadState(EPROM_FAN_LEVEL);
  Serial.print(F("Fan eprom state: "));
  Serial.print(currentFANlevel > 0 ? F("ON, ") : F("OFF, "));
  Serial.print(currentFANlevel);
  Serial.println(F("%"));
  analogWrite(MosFAN_PIN, currentFANlevel * 2.55 );
#endif

#if defined TEMPHUM_SENSOR
  // Start up SI7021 TempHum sensor
  si7021.initialize();
#endif

#if defined LUX_SENSOR
  // Start up BH1750 sensor
  lightSensor.begin();
#endif

#if defined DALLAS
  // Start up Dallas temperature probes
  dallas.begin();
#endif

  Serial.println(F("Node ready to receive messages"));

}


void presentation() {

  // Send the Sketch Version Information to the Gateway
  wait(MESSAGEWAIT);
  sendSketchInfo(SN, SV);

#if defined LED_CONTROL
  String ledReg = "LEDs " + Location;
  // Register the LED as a dimmable light with the gateway
  wait(MESSAGEWAIT);
  present(CHILD_ID_LED, S_DIMMER, ledReg.c_str());
#endif

#if defined FAN_CONTROL
  String fanReg = "Fan " + Location;
  // Register the Fan as a dimmable light with the gateway
  wait(MESSAGEWAIT);
  present(CHILD_ID_FAN, S_DIMMER, fanReg.c_str());
#endif

#if defined TEMPHUM_SENSOR
  String sitReg = "Temp " + Location;
  String sihReg = "Hum " + Location;
  wait(MESSAGEWAIT);
  present(CHILD_ID_TEMP, S_TEMP, sitReg.c_str());
  wait(MESSAGEWAIT);
  present(CHILD_ID_HUM, S_HUM, sihReg.c_str());
#endif

#if defined LUX_SENSOR
  String bhReg = "Lux " + Location;
  wait(MESSAGEWAIT);
  present(CHILD_ID_LUX, S_LIGHT_LEVEL, bhReg.c_str());
#endif

#if defined DALLAS
  // Fetch the number of attached temperature sensors
  numSensors = dallas.getDeviceCount();

  // Present all sensors to controller
  for (int i = CHILD_ID_DALLAS; i < numSensors + CHILD_ID_DALLAS; i++) {
    String dallasReg = "Temp " + Location + " " + String(i - CHILD_ID_DALLAS + 1);
    wait(MESSAGEWAIT);
    present(i, S_TEMP, dallasReg.c_str());
  }
#endif

  // Pull the current status from the controller
  Serial.println(F("Updating device status from the controller"));

#if defined LED_CONTROL
  wait(MESSAGEWAIT);
  request(CHILD_ID_LED, V_PERCENTAGE);
#endif

#if defined FAN_CONTROL
  wait(MESSAGEWAIT);
  request(CHILD_ID_FAN, V_PERCENTAGE);
#endif

}


void loop() {

  unsigned long currentMillis = millis();       // Start timer

#if defined TEMPHUM_SENSOR
  if (currentMillis - TempHumMillis >= SLEEP_TEMPHUM) {    // Every SLEEP_TIME fetch data from sensors and send to controller
    TempHumMillis = currentMillis;

    // Fetch temperature from sensor
    float temperature;
    si7021.getTemperature(temperature);
    temperature = round(temperature * 10) / 10.0; // 0.1°C accuracy is sensistive enough
    if (!metric) {
      temperature = temperature * 9.0 / 5.0 + 32.0;
    }
    wait(MESSAGEWAIT);
    send(msgTemp.set(temperature, 1));
#if defined MY_DEBUG
    Serial.print(F("Temperature: "));
    Serial.print(temperature);
    Serial.println(metric ? F(" °C") : F(" °F"));
#endif

    // Fetch humidity from sensor
    float humidity;
    si7021.getHumidity(humidity);
    humidity = round(humidity);     // 1% RH accuracy is sensistive enough
    // Clip humidity values to a valid range
    // If sent RH > 100% domoticz will ignore both temperature and humidity readings
    humidity = humidity > 100 ? 100 : humidity;
    humidity = humidity < 0   ? 0   : humidity;
    wait(MESSAGEWAIT);
    send(msgHum.set(humidity, 0));
#if defined MY_DEBUG
    Serial.print(F("Humidity: "));
    Serial.print(humidity);
    Serial.println(F(" %"));
#endif
  }
#endif

#if defined LUX_SENSOR
  if (currentMillis - LuxMillis >= SLEEP_LUX) {     // Every SLEEP_TIME fetch data from sensors and send to controller
    LuxMillis = currentMillis;
    // Fetch light from sensor
    uint16_t lux = lightSensor.readLightLevel();    // Get lux value
    wait(MESSAGEWAIT);
    send(msgLux.set(lux));
#if defined MY_DEBUG
    Serial.print(F("Light: "));
    Serial.print(lux);
    Serial.println(F(" lux"));
#endif
  }
#endif

#if defined DALLAS
  if (currentMillis - DallasMillis >= SLEEP_DALLAS) {    // Every SLEEP_TIME fetch data from sensors and send to controller
    DallasMillis = currentMillis;
    // call sensors.requestTemperatures() to issue a global temperature
    // request to all devices on the bus
#if defined MY_DEBUG
    Serial.print("Measuring  temperatures...");
#endif
    dallas.requestTemperatures(); // Send the command to get temperatures
#if defined MY_DEBUG
    Serial.println(" DONE");
#endif

    for (int i = 0; i < numSensors; i++) {
      // Fetch and round temperature to one decimal
      float temperature = static_cast<float>(static_cast<int>((getConfig().isMetric ? dallas.getTempCByIndex(i) : dallas.getTempFByIndex(i)) * 10.)) / 10.;
      if (temperature != -127.00 && temperature != 85.00) {
        // Send in the new temperature
        wait(MESSAGEWAIT);
        send(msgDallas.setSensor(CHILD_ID_DALLAS + i).set(temperature, 1));

#if defined MY_DEBUG
        // After we got the temperatures, we can print them.
        // We use the function ByIndex, and as an example get the temperature from the first sensor only.
        Serial.print("Temperature for the device ");
        Serial.print(i);
        Serial.print(" is: ");
        Serial.print(temperature);
        Serial.println(getConfig().isMetric ? "C" : "F");
#endif
      }
    }
  }
#endif

}


void receive(const MyMessage &message) {

  if (message.isAck()) {
#if defined MY_DEBUG
    Serial.println("ACK received");
#endif
  }

#if defined LED_CONTROL
  else if (((message.sensor == CHILD_ID_LED)) && (message.type == V_STATUS || message.type == V_PERCENTAGE)) {

    //  Retrieve the power or dim level from the incoming request message
    int requestedLevel = atoi(message.data);

    // Adjust incoming level if this is a V_LIGHT variable update [0 == off, 1 == on]
    requestedLevel *= (message.type == V_STATUS ? 100 : 1);

    // Clip incoming level to valid range of 0 to 100
    requestedLevel = requestedLevel > 100 ? 100 : requestedLevel;
    requestedLevel = requestedLevel < 0   ? 0   : requestedLevel;

#if defined MY_DEBUG
    Serial.print(F("Changing LED level from "));
    Serial.print(currentLEDlevel);
    Serial.print(F(" to "));
    Serial.println(requestedLevel);
#endif

    saveState(EPROM_LED_LEVEL, requestedLevel);
    //fadeToLEDLevel(requestedLevel);
    analogWrite(MosLED_PIN, requestedLevel * 2.55 );
    currentLEDlevel = requestedLevel;

    // Inform the gateway of the current dim level.
    wait(MESSAGEWAIT);
    send(msgPercLED.set(currentLEDlevel));
  }
#endif

#if defined FAN_CONTROL
  else if (((message.sensor == CHILD_ID_FAN)) && (message.type == V_STATUS || message.type == V_PERCENTAGE)) {

    //  Retrieve the power or dim level from the incoming request message
    int requestedLevel = atoi(message.data);

    // Adjust incoming level if this is a V_LIGHT variable update [0 == off, 1 == on]
    requestedLevel *= (message.type == V_STATUS ? 100 : 1);

    // Clip incoming level to valid range of 0 to 100
    requestedLevel = requestedLevel > 100 ? 100 : requestedLevel;
    requestedLevel = requestedLevel < 0   ? 0   : requestedLevel;

#if defined MY_DEBUG
    Serial.print(F("Changing Fan level from "));
    Serial.print(currentFANlevel);
    Serial.print(F(" to "));
    Serial.println(requestedLevel);
#endif

    saveState(EPROM_FAN_LEVEL, requestedLevel);
    analogWrite(MosFAN_PIN, requestedLevel * 2.55 );
    currentFANlevel = requestedLevel;

    // Inform the gateway of the current dim level.
    wait(MESSAGEWAIT);
    send(msgPercFAN.set(currentFANlevel));
  }
#endif

}


/**
    This method provides a graceful fade up/down effect for the LEDs
**/
void fadeToLEDLevel( int toLevel ) {
  int delta = ( toLevel - currentLEDlevel ) < 0 ? -1 : 1;

  while ( currentLEDlevel != toLevel ) {
    currentLEDlevel += delta;
    analogWrite(MosLED_PIN, fscale( 0, 100, 0, 255, currentLEDlevel, -2));  // Logarithmic dimming
    delay(FADE_DELAY);
  }
}

/* fscale
  Floating Point Autoscale Function V0.1
  Paul Badger 2007
  Modified from code by Greg Shakar
*/
float fscale( float originalMin, float originalMax, float newBegin, float newEnd, float inputValue, float curve)
{
  float   OriginalRange = 0;
  float   NewRange = 0;
  float   zeroRefCurVal = 0;
  float   normalizedCurVal = 0;
  float   rangedValue = 0;
  boolean invFlag = 0;

  // condition curve parameter
  // limit range
  if (curve > 10) curve = 10;
  if (curve < -10) curve = -10;

  curve = (curve * -.1) ; // - invert and scale - this seems more intuitive - postive numbers give more weight to high end on output
  curve = pow(10, curve); // convert linear scale into lograthimic exponent for other pow function

  // Check for out of range inputValues
  if (inputValue < originalMin) {
    inputValue = originalMin;
  }
  if (inputValue > originalMax) {
    inputValue = originalMax;
  }

  // Zero Refference the values
  OriginalRange = originalMax - originalMin;

  if (newEnd > newBegin) {
    NewRange = newEnd - newBegin;
  } else {
    NewRange = newBegin - newEnd;
    invFlag = 1;
  }

  zeroRefCurVal = inputValue - originalMin;
  normalizedCurVal  =  zeroRefCurVal / OriginalRange;   // normalize to 0 - 1 float

  // Check for originalMin > originalMax  - the math for all other cases i.e. negative numbers seems to work out fine
  if (originalMin > originalMax ) {
    return 0;
  }

  if (invFlag == 0) {
    rangedValue =  (pow(normalizedCurVal, curve) * NewRange) + newBegin;
  } else { // invert the ranges
    rangedValue =  newBegin - (pow(normalizedCurVal, curve) * NewRange);
  }

  return rangedValue;
}

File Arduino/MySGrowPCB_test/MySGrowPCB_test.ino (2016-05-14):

// CS eeprom pin
#define FLASH_SS 8        // D8

// The pin the ATSHA204 is connected on
#define ATSHA204_PIN 17   // A3

// OneWire pin
#define ONE_WIRE_BUS 4    // D4

#include <SPIFlash.h>     // From https://github.com/mysensors/Arduino/tree/development/libraries/SPIFlash as of May 2016 original from https://github.com/LowPowerLab/SPIFlash do not work with arduino 1.6.x
#include <sha204_library.h>
#include <sha204_lib_return_codes.h>
#include <SPI.h>
#include <OneWire.h>
#include <DallasTemperature.h>

SPIFlash flash(FLASH_SS);
const int sha204Pin = ATSHA204_PIN;
atsha204Class sha204(sha204Pin);

OneWire oneWire(ONE_WIRE_BUS);
DallasTemperature sensors(&oneWire);

void setup() {
  Serial.begin(115200);
  sensors.begin();
  pinMode(5, OUTPUT);
  pinMode(6, OUTPUT);
  pinMode(LED_BUILTIN, OUTPUT);
  digitalWrite(LED_BUILTIN, HIGH);
  analogWrite(5, 0);
  analogWrite(6, 0);
  analogWrite(13, 0 );

  uint8_t tx_buffer[SHA204_CMD_SIZE_MAX];
  uint8_t rx_buffer[SHA204_RSP_SIZE_MAX];
  uint8_t key[32];
  uint8_t ret_code;
  uint8_t lockConfig = 0;
  uint8_t lockValue = 0;
  uint16_t crc;

  Serial.println(F("----------------------------------------------------"));
  Serial.println(F("-------- MySGrowLED: optional hardware test --------"));
  Serial.println(F("----------------------------------------------------"));
  Serial.println("Dallas sensor");
  sensors.requestTemperatures(); // Send the command to get temperatures
  float temperature = sensors.getTempCByIndex(0);
  if (temperature != -127.00 && temperature != 85.00) {
    Serial.print("Current temperature: ");
    Serial.print(temperature);
    Serial.println("°C");
  } else {
    Serial.println("Not found");
  }
  Serial.print(F("--------------------------"));

  Serial.println(F("--------------------------"));
  Serial.println(F("ATSHA204"));

  // Wake device before starting operations
  ret_code = sha204.sha204c_wakeup(rx_buffer);
  if (ret_code != SHA204_SUCCESS)
  {
    Serial.println(F("Not found"));
  }
  else {
    // Output device revision on console
    ret_code = sha204.sha204m_dev_rev(tx_buffer, rx_buffer);
    if (ret_code != SHA204_SUCCESS)
    {
      Serial.print(F("Failed to determine device revision. Response: ")); Serial.println(ret_code, HEX);
    }
    Serial.print(F("Device revision: "));
    for (int i = 0; i < 4; i++)
    {
      if (rx_buffer[SHA204_BUFFER_POS_DATA + i] < 0x10)
      {
        Serial.print('0'); // Because Serial.print does not 0-pad HEX
      }
      Serial.print(rx_buffer[SHA204_BUFFER_POS_DATA + i], HEX);
    }
    Serial.println();

    // Output serial number on console
    ret_code = sha204.getSerialNumber(rx_buffer);
    if (ret_code != SHA204_SUCCESS)
    {
      Serial.print(F("Failed to obtain device serial number. Response: ")); Serial.println(ret_code, HEX);
    }
    else
    {
      Serial.print(F("Device serial:   "));
      for (int i = 0; i < 9; i++)
      {
        if (rx_buffer[i] < 0x10)
        {
          Serial.print('0'); // Because Serial.print does not 0-pad HEX
        }
        Serial.print(rx_buffer[i], HEX);
      }
      Serial.println();
    }
  }

  Serial.print(F("--------------------------"));

  Serial.println(F("--------------------------"));
  Serial.println(F("Eeprom"));
  flash.initialize();
  if (flash.readDeviceId() != 0)
  {
    Serial.print(F("Device ID: "));
    Serial.println(flash.readDeviceId(), HEX);
  }
  else {
    Serial.println(F("Not found"));
  }
  Serial.println(F("----------------------------------------------------"));
  Serial.println(F(""));
  Serial.println(F(""));

  delay(2500);

  Serial.println(F("----------------------------------------------------"));
  Serial.println(F("------------- MySGrowLED: mosfets test -------------"));
  Serial.println(F("----------------------------------------------------"));
}

void loop() {
  Serial.println(F("LED: on - Fan: off - Onboard LED: on"));
  analogWrite(5, 255);
  analogWrite(6, 0);
  digitalWrite(LED_BUILTIN, HIGH);
  delay(10000);
  Serial.println(F("LED: off - Fan: on - Onboard LED: off"));
  analogWrite(5, 0);
  analogWrite(6, 255);
  digitalWrite(LED_BUILTIN, LOW);
  delay(10000);
}

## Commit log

2016-04-28 Initial release
    Readme, guide and picture to build the LED fixture
2016-05-09 PCB received, seems ok.
    PCB description, ordering and assembly.
2016-05-09 Gerbers and BOM
    [MySGrowLED-B.Mask.gbs, MySGrowLED-B.SilkS.gbo, MySGrowLED-Bottom.gbl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]
2016-05-09 Rename edge cut file
    Renamed from .gm1 to .gko
    [MySGrowLED-Edge.Cuts.gko]
2016-05-14 BOM, test program
    Forgot BOM.
    Test program improved, added DS18b20 test.
    [MySGrowLED_BOM.xlsx]
2016-11-23 MySensors V2.0 update
    Arduino code updated to be compatible with MySensors V2.0 update
2016-12-09 DirtyPCBs link update
    Link to DirtyPCBs board updated for the new website.
2016-12-09 BOM update
    Resistors switched to 5% tolerance
    [MySGrowLED_BOM.xlsx]
